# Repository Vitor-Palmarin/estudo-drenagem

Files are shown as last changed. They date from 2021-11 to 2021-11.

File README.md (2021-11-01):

# Automação de bancada experimental para determinação de percolação de água em minério de ferro

O grande fluxo de mercadorias ao redor do mundo é algo vital para a economia mundial, e com isso se faz necessário um transporte que possibilite uma grande movimentação de carga e com um bom custo-benefício. As malhas ferroviárias são uma ótima opção para fazer o transporte de cargas de grande porte, como grãos, minérios, entre outros, permitindo assim, uma conexão direta entre vários pontos de produção, desde a extração da obra-prima até a exportação do produto nos portos. O transporte de minérios é feito em vagões abertos, causando um acúmulo de água desnecessária sobre o material em épocas de chuva, e a fim de solucionar essa problemática, está sendo estudado o uso de drenos para fazer o escoamento de água livre. O uso de drenos para fazer o escoamento de água livre sofre constantes entupimentos, necessitando de paradas no transporte onerosas para sua desobstrução. 
Foi desenvolvido um protótipo de bancada experimental para o estudo do sistema de drenagem em amostras do minério de ferro do tipo Sinter feed com diferentes concentrações mássicas, utilizando uma bancada experimental desenvolvida com drenos confeccionados em ABS por uma impressora 3D. 

A automação da bancada utilizou um microcontrolador ATmega, que por meio de sensores de ultrassom foi medida a altura do fluído e armazenada os resultados da medição em um arquivo de extensão CSV por meio de um cartão Micro SD, durante um intervalo definido previamente definido, com exibição da coleta em tempo real em um display LCD.

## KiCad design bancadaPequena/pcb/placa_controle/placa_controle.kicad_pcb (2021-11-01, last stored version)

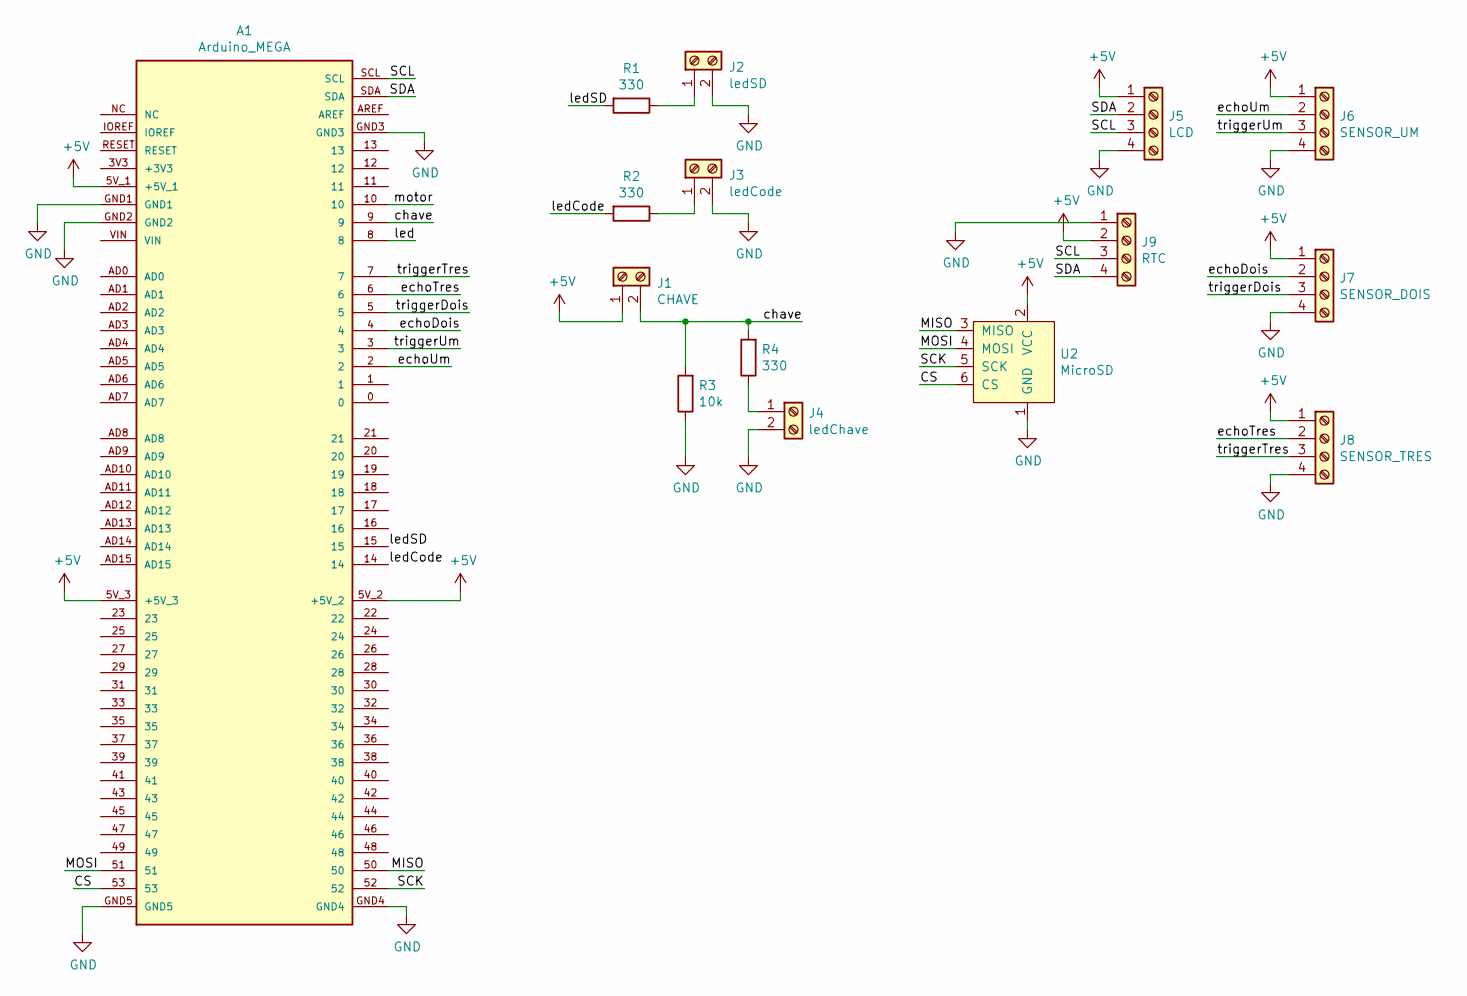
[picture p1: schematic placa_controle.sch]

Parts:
A1: Arduino_MEGA
J1: CHAVE; Altech_AK300_1x02_P5.00mm_45-Degree
J2: ledSD; PinSocket_1x02_P2.54mm_Vertical
J3: ledCode; PinSocket_1x02_P2.54mm_Vertical
J4: ledChave; PinSocket_1x02_P2.54mm_Vertical
J5: LCD; Altech_AK300_1x04_P5.00mm_45-Degree
J6: SENSOR_UM; Altech_AK300_1x04_P5.00mm_45-Degree
J7: SENSOR_DOIS; Altech_AK300_1x04_P5.00mm_45-Degree
J8: SENSOR_TRES; Altech_AK300_1x04_P5.00mm_45-Degree
J9: RTC; PinSocket_1x04_P2.54mm_Vertical
R1, R2, R4: 330; R_Axial_DIN0207_L6.3mm_D2.5mm_P10.16mm_Horizontal
R3: 10k; R_Axial_DIN0207_L6.3mm_D2.5mm_P10.16mm_Horizontal
U2: MicroSD; PinSocket_1x06_P2.54mm_Vertical

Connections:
+5V: A1.5V_1 (+5V_1), A1.5V_2 (+5V_2), A1.5V_3 (+5V_3), J1.1, J5.1, J6.1, J7.1, J8.1, J9.2, U2.2 (VCC)
/CS: A1.53, U2.6 (CS)
/MISO: A1.50, U2.3 (MISO)
/MOSI: A1.51, U2.4 (MOSI)
/SCK: A1.52, U2.5 (SCK)
/SCL: A1.SCL, J5.3, J9.3
/SDA: A1.SDA, J5.2, J9.4
/chave: A1.9, J1.2, R3.2, R4.2
/echoDois: A1.4, J7.2
/echoTres: A1.6, J8.2
/echoUm: A1.2, J6.2
/led: A1.8
/ledCode: A1.14, R2.2
/ledSD: A1.15, R1.2
/motor: A1.10
/triggerDois: A1.5, J7.3
/triggerTres: A1.7, J8.3
/triggerUm: A1.3, J6.3
GND: A1.GND1, A1.GND2, A1.GND3, A1.GND4, A1.GND5, J2.2, J3.2, J4.2, J5.4, J6.4, J7.4, J8.4, J9.1, R3.1, U2.1 (GND)
unnamed: J2.1, R1.1
unnamed: J3.1, R2.1
unnamed: J4.1, R4.1

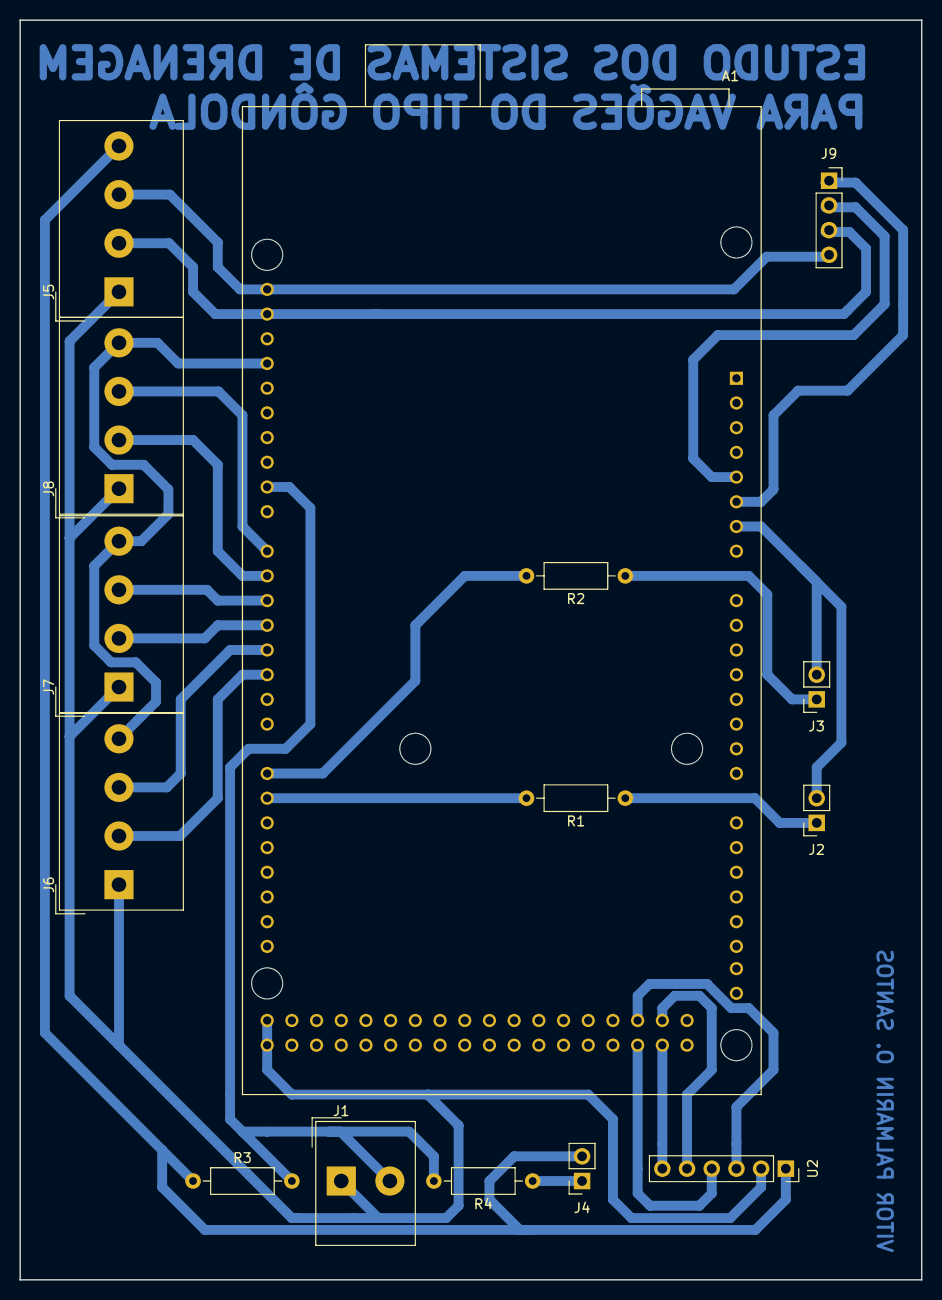
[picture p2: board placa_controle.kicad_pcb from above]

Board: 2 copper layers, 92.7 x 129.5 mm, 15 parts (0 on the bottom side), 20 nets.

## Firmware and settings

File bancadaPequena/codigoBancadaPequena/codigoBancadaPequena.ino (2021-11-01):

/* BANCADA EXPERIMENTAL PARA ESTUDO DOS SISTEMAS DE DRENAGEM PARA VAGÕES DE CARGA TIPO GÔNDOLA
 * 
 * DESENVOLVIDO POR: VITOR PALMARIN OLIVEIRA SANTOS - 10/2021
 * 
 */
// === DECLARACAO DE BIBLIOTECAS ===
#include <SPI.h>
#include <SD.h>
#include <Wire.h>;
#include <LiquidCrystal_I2C.h>;

// === DECLARAÇÃO DE OBJETOS ===
LiquidCrystal_I2C lcd(0x27, 20, 4);

// === PINAGEM ===
const int chipSelect = 10;

const int triggerUm = 2;
const int echoUm = 3;

const int triggerDois = 4;
const int echoDois = 5;

const int triggerTres = 6;
const int echoTres = 7;

const int led = 9;

const int chave = 8;

// === VARIAVEIS ===
long intervaloColeta = millis();
long intervaloLed = millis();
long intervaloExibicao = millis();

long pulsoUm, 
     pulsoDois, 
     pulsoTres;

int nivelUm, 
    nivelDois, 
    nivelTres;

const int alturaTanque = 506; // altura do tanque em milimetros

bool opcao = 0;

void setup()
{
  Serial.begin(9600);
  lcd.init();
  lcd.backlight();

  pinMode(triggerUm, OUTPUT);
  pinMode(echoUm, INPUT); 
  pinMode(triggerDois, OUTPUT);
  pinMode(echoDois, INPUT);
  pinMode(triggerTres, OUTPUT);
  pinMode(echoTres, INPUT);
  pinMode(led, OUTPUT);
  pinMode(chave, INPUT);

  digitalWrite(triggerUm, LOW);
  digitalWrite(triggerDois, LOW);
  digitalWrite(triggerTres, LOW);
  digitalWrite(led, LOW);
  
  Serial.println("Inicializando cartao SD...");
  if (!SD.begin(chipSelect))
  {
    Serial.println("Falha ao acessar o cartao !");
    Serial.println("Verifique o cartao/conexoes e reinicie o Arduino...");
    return;
  }
  Serial.println("Cartao iniciado corretamente !\n");
}

void loop()
{
  if((millis() - intervaloLed) >= 500){    // pisca o led no intervalo de 0,5 segundo
    intervaloLed = millis();
    digitalWrite(led,!digitalRead(led));
  }

  if((millis() - intervaloExibicao) >= 1000){   // exibe os dados no Serial a cada 1 segundo
    intervaloExibicao = millis();
    
    nivelUm = getDistancia(triggerUm, echoUm);
    nivelDois = getDistancia(triggerDois, echoDois);
    nivelTres = getDistancia(triggerTres, echoTres);

    exibeLCD();
    exibeSerial();
  }
  
  if((millis() - intervaloColeta) >= 60000){ // faz a coleta de dados a cada 1 minuto
    intervaloColeta = millis();
    if(digitalRead(chave)){
      saveData();                           // armazena os dados coletados na planilha
    }
  }
}

void exibeLCD(){
  lcd.clear();   
  lcd.setCursor(0,0);
  lcd.print("TEMPO = ");
  lcd.setCursor(8,0);
  lcd.print(millis()/1000);
  
  lcd.setCursor(0,1);
  lcd.print("SENSOR 1 = ");
  lcd.setCursor(11,1);
  lcd.print(nivelUm);
  
  lcd.setCursor(0,2);
  lcd.print("SENSOR 2 = ");
  lcd.setCursor(11,2);
  lcd.print(nivelDois);
  
  lcd.setCursor(0,3);
  lcd.print("SENSOR 3 = ");
  lcd.setCursor(11,3);
  lcd.print(nivelTres);
}

void exibeSerial(){
  Serial.println();
  Serial.print("TEMPO = ");
  Serial.print(millis()/1000);
  Serial.print(" s = ");
  Serial.print(millis()/60000);
  Serial.println(" min");
  Serial.println();
  
  // SENSOR 1
  Serial.print("Sensor 1 = ");
  Serial.print(nivelUm);
  Serial.println(" mm ");
  // SENSOR 2
  Serial.print("Sensor 2 = ");
  Serial.print(nivelDois);
  Serial.println(" mm ");
  
  // SENSOR 3
  Serial.print("Sensor 3 = ");
  Serial.print(nivelTres);
  Serial.println(" mm ");
  
  Serial.println();
}

long getDistancia(int trigger, int echo) {
    digitalWrite(trigger, HIGH);
    delayMicroseconds(5);
    digitalWrite(trigger, LOW);
    long pulso = pulseIn(echo, HIGH);
    long distanciaSensor = pulso / 2.9 / 2;
    if(opcao == 1) {        // opcao 1 = retorna o nivel do tanque a partir do fundo
      return alturaTanque - distanciaSensor;
    }
    else {                  // opcao 0 = retorna o nivel do tanque a partir do sensor
      return distanciaSensor;
    }
}

void saveData(){
  String fileName = "/datalog.csv";
  if(!SD.exists(fileName)){
    File file = SD.open(fileName, FILE_WRITE);
    if(!file){
      Serial.println("Failed to open file for writing");
      return;
    }
    if(file.println("ESTUDO DE DRENAGEM PARA VAGOES DE CARGA TIPO GONDOLA - UNISANTA")){
      Serial.println("File written");
    } else {
      Serial.println("Write failed");
    }
    if(file.println("DATA;HORA;TEMPO;SENSOR 1 [mm];SENSOR 2 [mm];SENSOR 3 [mm]")){
      Serial.println("Message appended");
    } else {
      Serial.println("Append failed");
    }
    if(file.println(";;" + String(millis()/60000) + ";" + String(nivelUm) + ";" + String(nivelDois) + ";" + String(nivelTres))){
      Serial.println("Message appended");
    } else {
      Serial.println("Append failed");
    }
    file.close();
  }
  else{
    File file = SD.open(fileName, FILE_WRITE);
    if(!file){
      Serial.println("Failed to open file for appending");
      return;
    }
    if(file.println(";;" + String(millis()/60000) + ";" + String(nivelUm) + ";" + String(nivelDois) + ";" + String(nivelTres))){
      Serial.println("Message appended");
    } else {
      Serial.println("Append failed");
    }
    file.close();
  }
}
